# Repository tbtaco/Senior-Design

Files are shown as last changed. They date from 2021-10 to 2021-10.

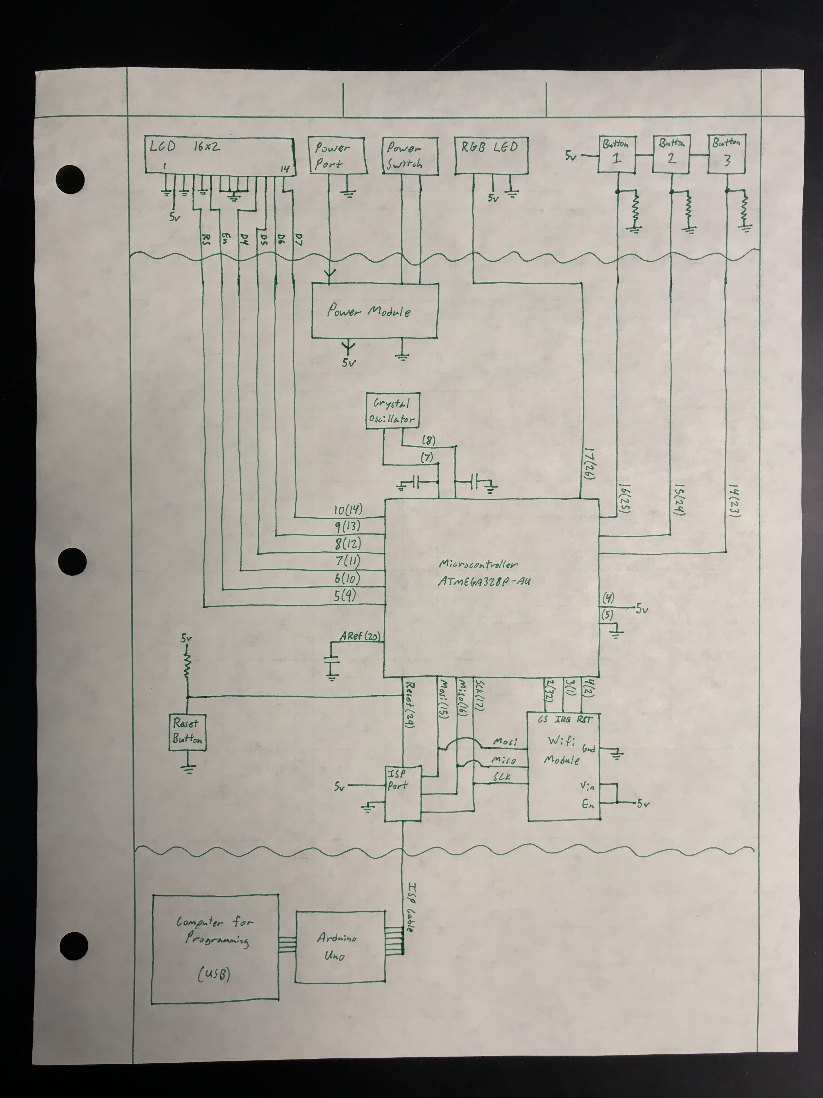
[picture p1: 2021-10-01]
Other Resources/Hand Drawn Early Schematic.jpeg

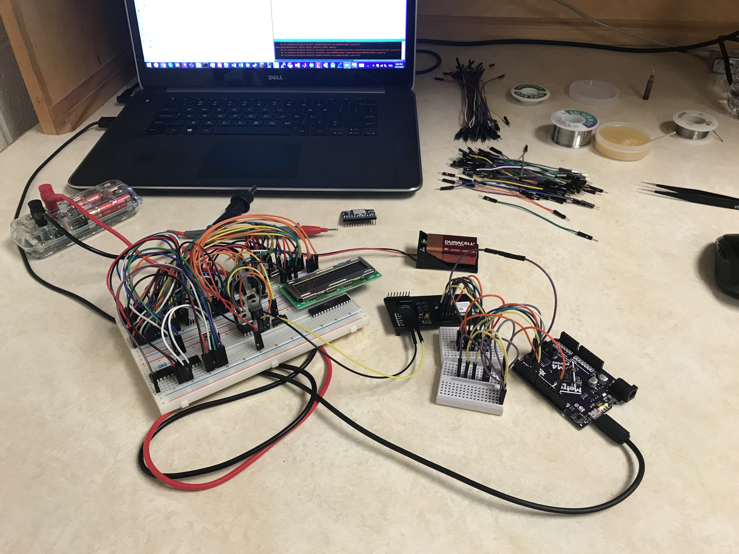
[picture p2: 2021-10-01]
Other Resources/Testing Proto 1.JPG

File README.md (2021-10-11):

The Senior Design project I was able to be a part of in Fall 2019 and Spring 2020 at K-State was the "MAC Address Finder".  For that, I worked in a group of 4 to fully design and build our device.  My role was mainly designing the circuit and building the board containing the microcontroller, and the board with the Wi-Fi module.  The device is needed in the residence halls for IT staff to quickly get certain device's MAC addresses.  The main reason for needing this device is the Google Home Mini.  They normally don't have a printed MAC address on the outside of the product and must be connected to a network to retrieve the address.  Our device creates that network to connect to and gives a very easy way to see this address.  The MAC address can then be used to manually add the device to the university network.

Schematics and board layouts can be found in the [EAGLE](https://github.com/tbtaco/Senior-Design/tree/main/EAGLE) directory.  The 3 main folders in there represent the separate orders I placed.  The final versions of each board I designed are:

[Main Board](https://github.com/tbtaco/Senior-Design/tree/main/EAGLE/Batch%201/Main%20Board) - This was the first version of the main PCB and I intended on redoing it at some point but it never happened due to budget constraints, time constraints, and Covid-19's impact on everything.
    
[Wifi Board](https://github.com/tbtaco/Senior-Design/tree/main/EAGLE/Batch%203/Wifi%20Board%20Rework) - I had the Wi-Fi portion working on a breadboard for the most part and turned that into a PCB.  There were some inconsistencies with different online documentation that messed up a couple things with my first version of the Wi-Fi board PCB.  We didn't have time for several attempts so I designed some breakout boards to test things before ordering the final version of this board.  The final version has several switches for debugging just in case things went horribly wrong which could easily be removed if another version were possibe.
    
[Button Board](https://github.com/tbtaco/Senior-Design/tree/main/EAGLE/Batch%201/Button%20Board) - A rather simple board that has an RGB LED and 3 buttons for input.
    
[Programmer Board](https://github.com/tbtaco/Senior-Design/tree/main/EAGLE/Batch%202/Programmer%20Board) - After several redesigns, this is the final board I created to assist with programming the microcontroller and Wi-Fi module.  It fits on top of an Arduino Uno for programming the microcontroller, and on top of a Metro M4 Express for programming the Wi-Fi module.

I also wrote the code to go on the microcontroller.  I hadn't intended on writing the final code for this project but it sort of just happened as I needed it for testing and we were short on time toward the end of semester.  This Arduino file along with the two edited programs for programming the boards can be found in the [Arduino](https://github.com/tbtaco/Senior-Design/tree/main/Arduino) directory.

I have some additional pictures and screenshots that don't fit in one of the two categories above, so I put them in the [Other Resources](https://github.com/tbtaco/Senior-Design/tree/main/Other%20Resources) directory.

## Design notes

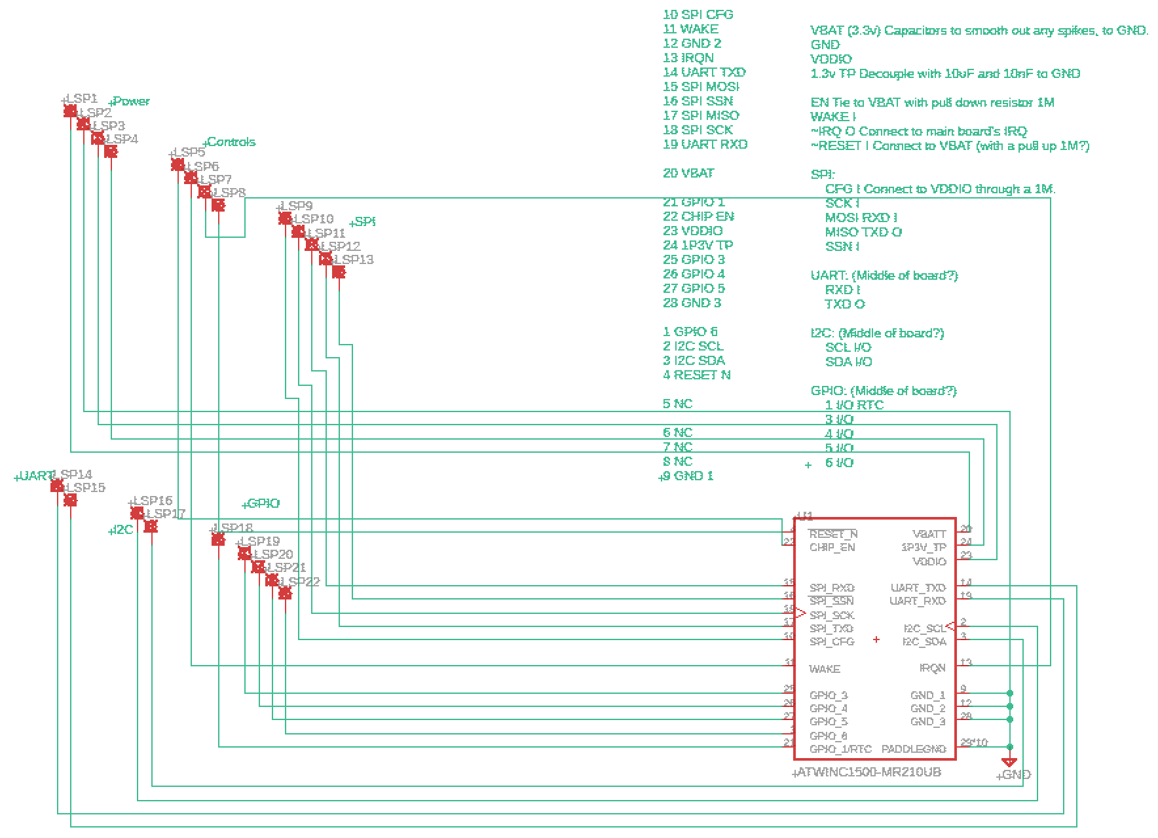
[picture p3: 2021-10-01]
EAGLE/Batch 2/Wifi Module Breakout/Wifi Module Breakout Schematic.png

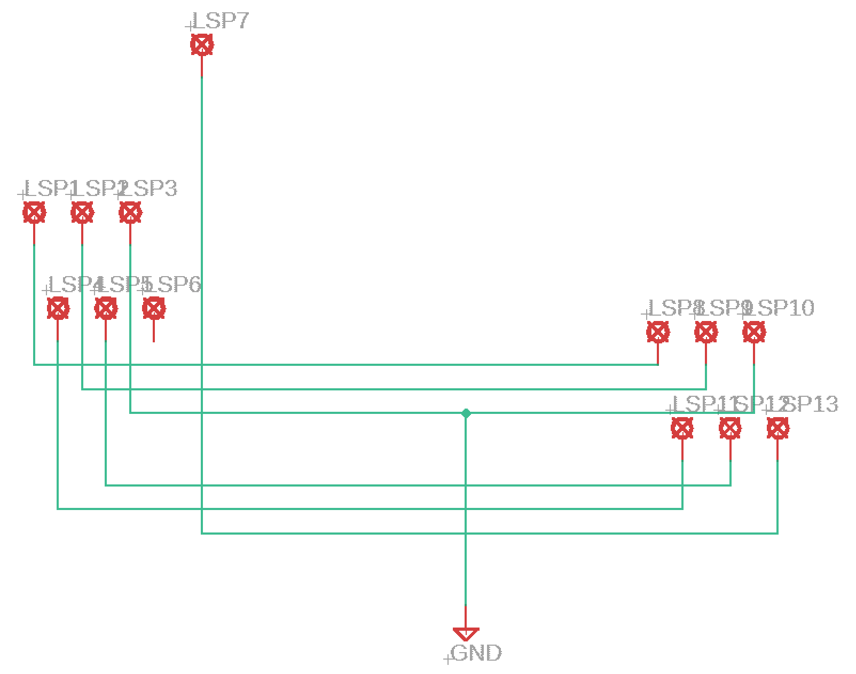
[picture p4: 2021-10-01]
EAGLE/Batch 1/Programmer Board/Programmer Board Schematic.png

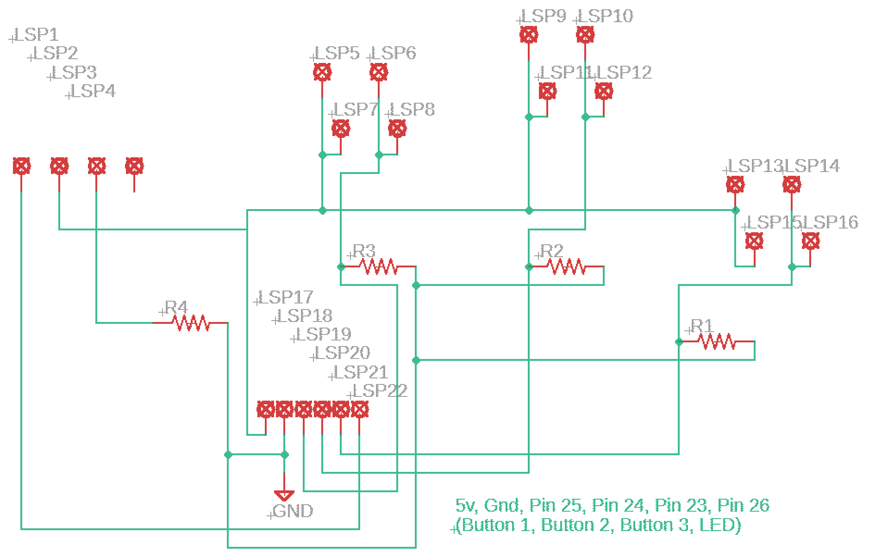
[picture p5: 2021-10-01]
EAGLE/Batch 1/Button Board/Button Board Schematic.png

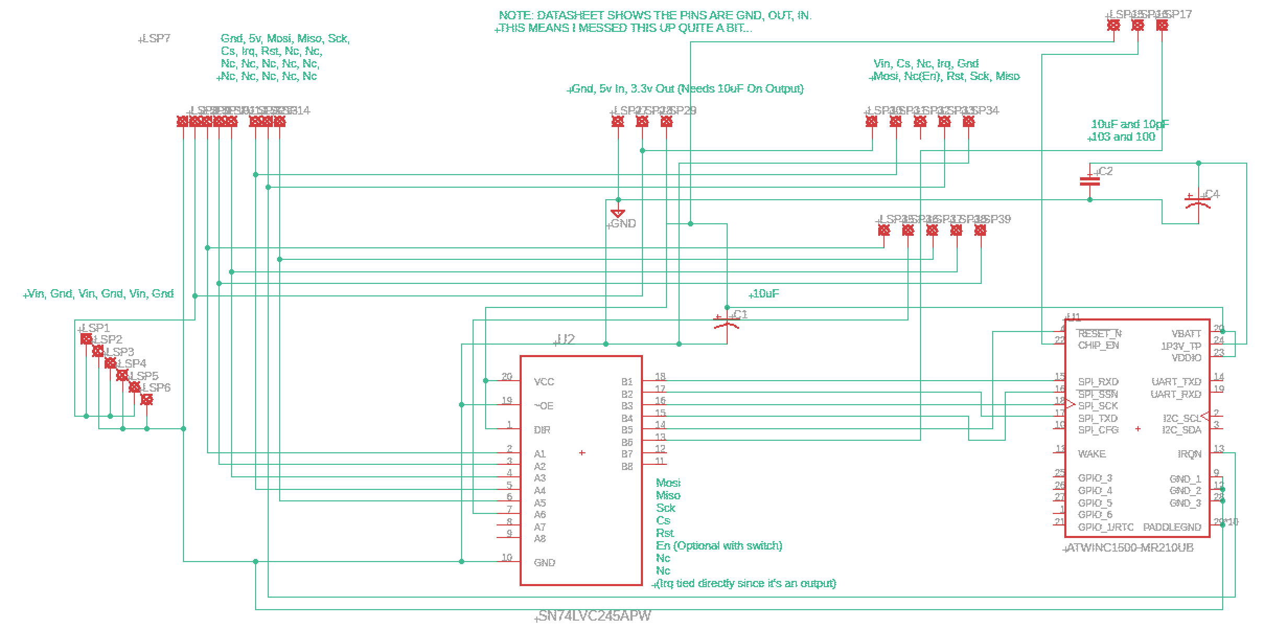
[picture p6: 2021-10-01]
EAGLE/Batch 1/Wifi Board/Wifi Board Schematic.png

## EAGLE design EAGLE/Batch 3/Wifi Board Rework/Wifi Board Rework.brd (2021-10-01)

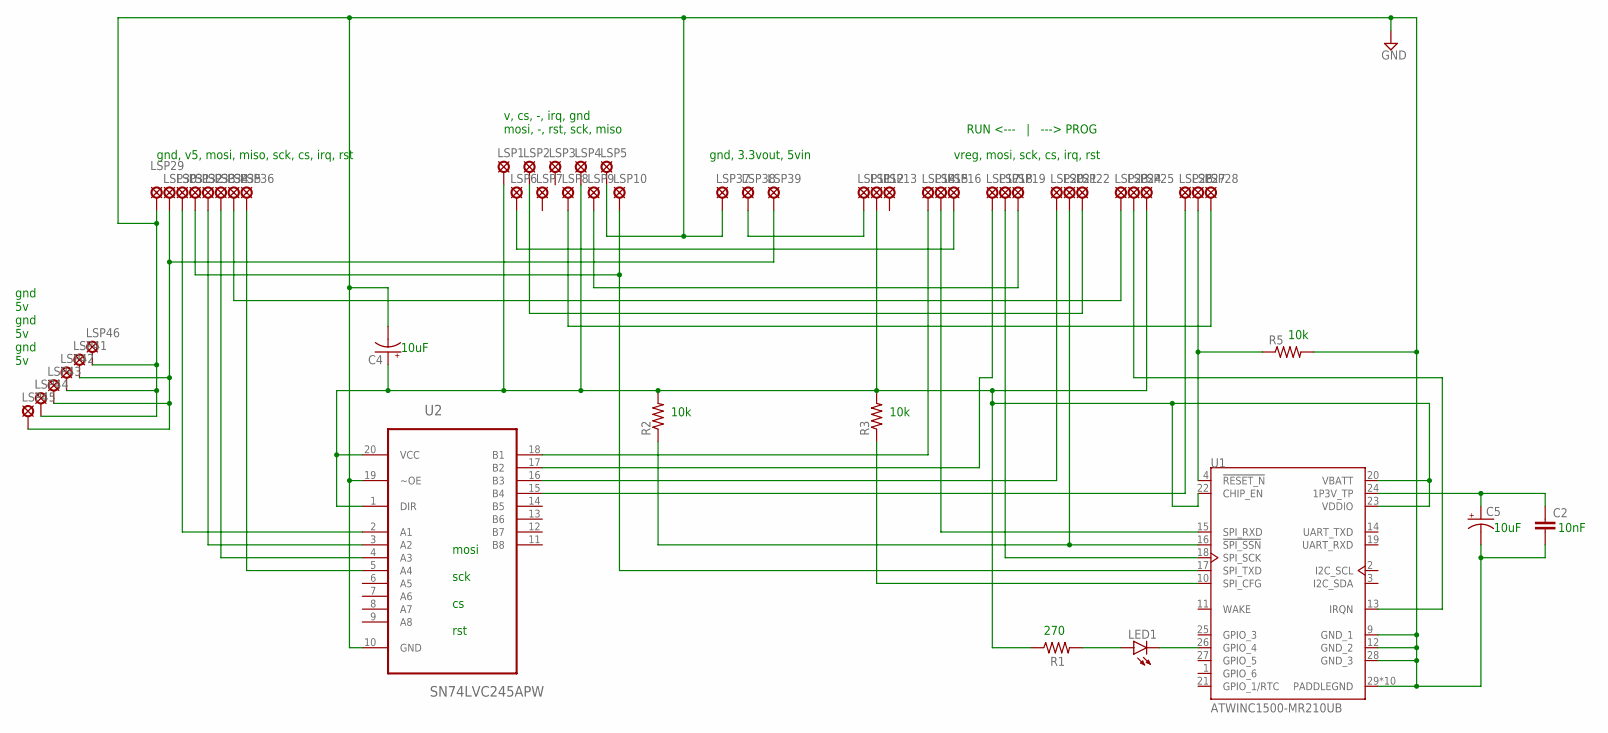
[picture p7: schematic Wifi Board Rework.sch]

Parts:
C2: C5/2.5; C5B2.5
C4, C5: CPOL-USE2-4; E2-4
LED1: LED5MM
LSP1, LSP2, LSP3, LSP4, LSP5, LSP7, LSP8, LSP9, LSP10, LSP11, LSP12, LSP13, LSP14, LSP15, LSP16, LSP17, LSP18, LSP19, LSP20, LSP21, LSP22, LSP23, LSP24, LSP25, LSP26, LSP27, LSP28, LSP30, LSP31, LSP32, LSP33, LSP34, LSP35, LSP36, LSP38, LSP39, LSP41, LSP42, LSP43, LSP44, LSP45: LSP10_CLSP10_C; LSP10_C
LSP6, LSP29, LSP37, LSP46: LSP10_S
R1, R2, R3, R5: R-US_VMTA55; VMTA55
U1: ATWINC1500-MR210UB; MICROCHIP_ATWINC1500-MR210UB
U2: SN74LVC245APW; SOP65P640X120-20N

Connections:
GND: C2.2, C4.-, C5.-, LSP5.P$1, LSP29.P$1, LSP37.P$1, LSP42.P$1, LSP44.P$1, LSP46.P$1, R5.2, U1.9 (GND_1), U1.12 (GND_2), U1.28 (GND_3), U1.29 (PADDLEGND), U1.P$1 (PADDLEGND), U1.P$2 (PADDLEGND), U1.P$3 (PADDLEGND), U1.P$4 (PADDLEGND), U1.P$5 (PADDLEGND), U1.P$6 (PADDLEGND), U1.P$7 (PADDLEGND), U1.P$8 (PADDLEGND), U1.P$9 (PADDLEGND), U2.10 (GND), U2.19 (~OE)
unnamed: LED1.K (C), U1.26 (GPIO_4)
unnamed: LED1.A, R1.2
unnamed: C4.+, LSP1.P$1, LSP4.P$1, LSP12.P$1, LSP25.P$1, R1.1, R2.2, R3.2, U1.20 (VBATT), U1.22 (CHIP_EN), U1.23 (VDDIO), U2.1 (DIR), U2.20 (VCC)
unnamed: LSP11.P$1, LSP38.P$1
unnamed: R3.1, U1.10 (SPI_CFG)
unnamed: LSP10.P$1, LSP32.P$1, U1.17 (SPI_TXD)
unnamed: LSP30.P$1, LSP39.P$1, LSP41.P$1, LSP43.P$1, LSP45.P$1
unnamed: LSP23.P$1, LSP35.P$1
unnamed: LSP15.P$1, U1.15 (SPI_RXD)
unnamed: LSP6.P$1, LSP16.P$1
unnamed: LSP9.P$1, LSP19.P$1
unnamed: LSP2.P$1, LSP22.P$1
unnamed: LSP24.P$1, U1.13 (IRQN)
unnamed: C2.1, C5.+, U1.24 (1P3V_TP)
unnamed: LSP14.P$1, U2.18 (B1)
unnamed: LSP17.P$1, U2.17 (B2)
unnamed: LSP20.P$1, U2.16 (B3)
unnamed: LSP26.P$1, U2.15 (B4)
unnamed: LSP27.P$1, R5.1, U1.4 (!RESET_N)
unnamed: LSP34.P$1, U2.4 (A3)
unnamed: LSP18.P$1, U1.18 (SPI_SCK)
unnamed: LSP21.P$1, R2.1, U1.16 (!SPI_SSN)
unnamed: LSP36.P$1, U2.5 (A4)
unnamed: LSP33.P$1, U2.3 (A2)
unnamed: LSP31.P$1, U2.2 (A1)
unnamed: LSP8.P$1, LSP28.P$1

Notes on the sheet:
v, cs, -, irq, gnd mosi, -, rst, sck, miso
vreg, mosi, sck, cs, irq, rst
gnd, v5, mosi, miso, sck, cs, irq, rst
10k
10uF
10nF
270
gnd, 3.3vout, 5vin
RUN <--- | ---> PROG
gnd 5v gnd 5v gnd 5v
mosi sck cs rst

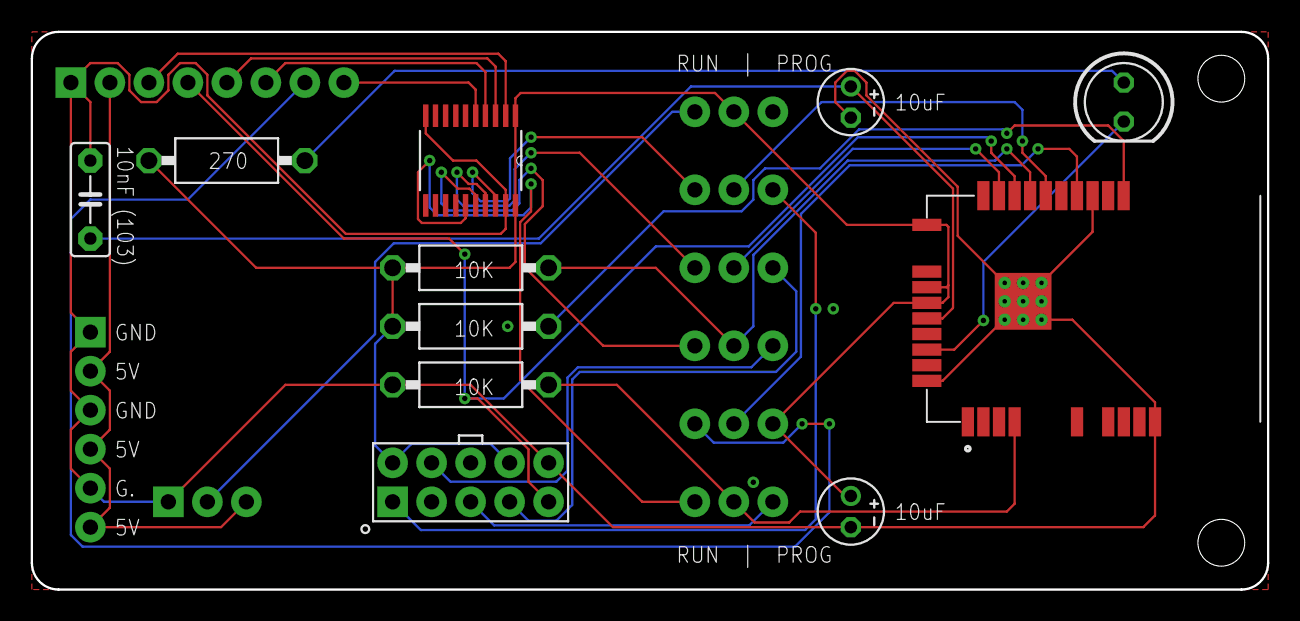
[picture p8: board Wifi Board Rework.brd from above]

Board: 2 copper layers, 80.5 x 36.3 mm, 55 parts (0 on the bottom side), 27 nets.

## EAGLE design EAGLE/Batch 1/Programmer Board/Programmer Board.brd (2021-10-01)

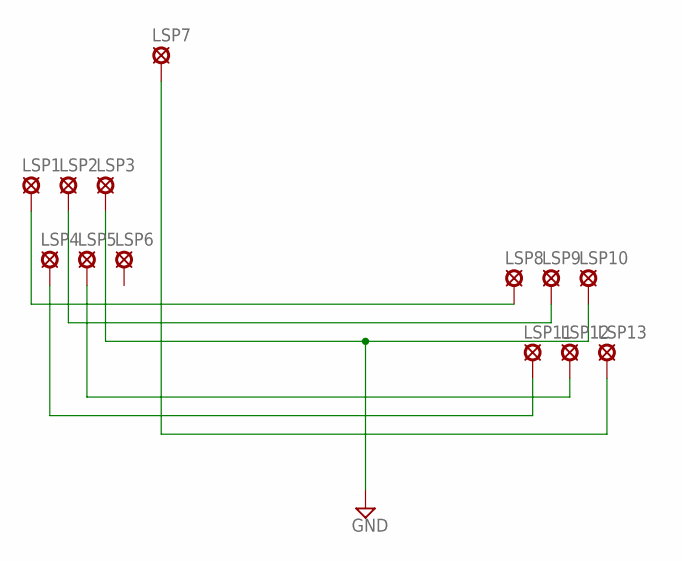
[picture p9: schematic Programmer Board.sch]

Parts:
LSP1, LSP2, LSP3, LSP4, LSP5, LSP6, LSP7, LSP8, LSP9, LSP10, LSP11, LSP12, LSP13: LSP10_CLSP10_C; LSP10_C

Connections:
GND: LSP3.P$1, LSP10.P$1
unnamed: LSP1.P$1, LSP8.P$1
unnamed: LSP2.P$1, LSP9.P$1
unnamed: LSP4.P$1, LSP11.P$1
unnamed: LSP5.P$1, LSP12.P$1
unnamed: LSP7.P$1, LSP13.P$1

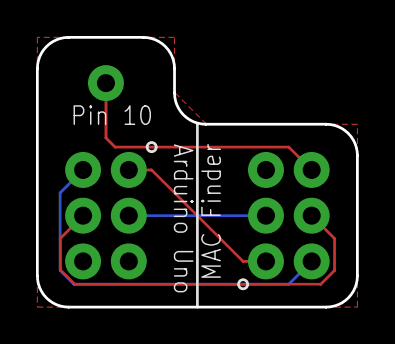
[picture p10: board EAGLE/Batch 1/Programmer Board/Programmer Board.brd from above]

Board: 2 copper layers, 17.8 x 15.0 mm, 13 parts (0 on the bottom side), 6 nets.

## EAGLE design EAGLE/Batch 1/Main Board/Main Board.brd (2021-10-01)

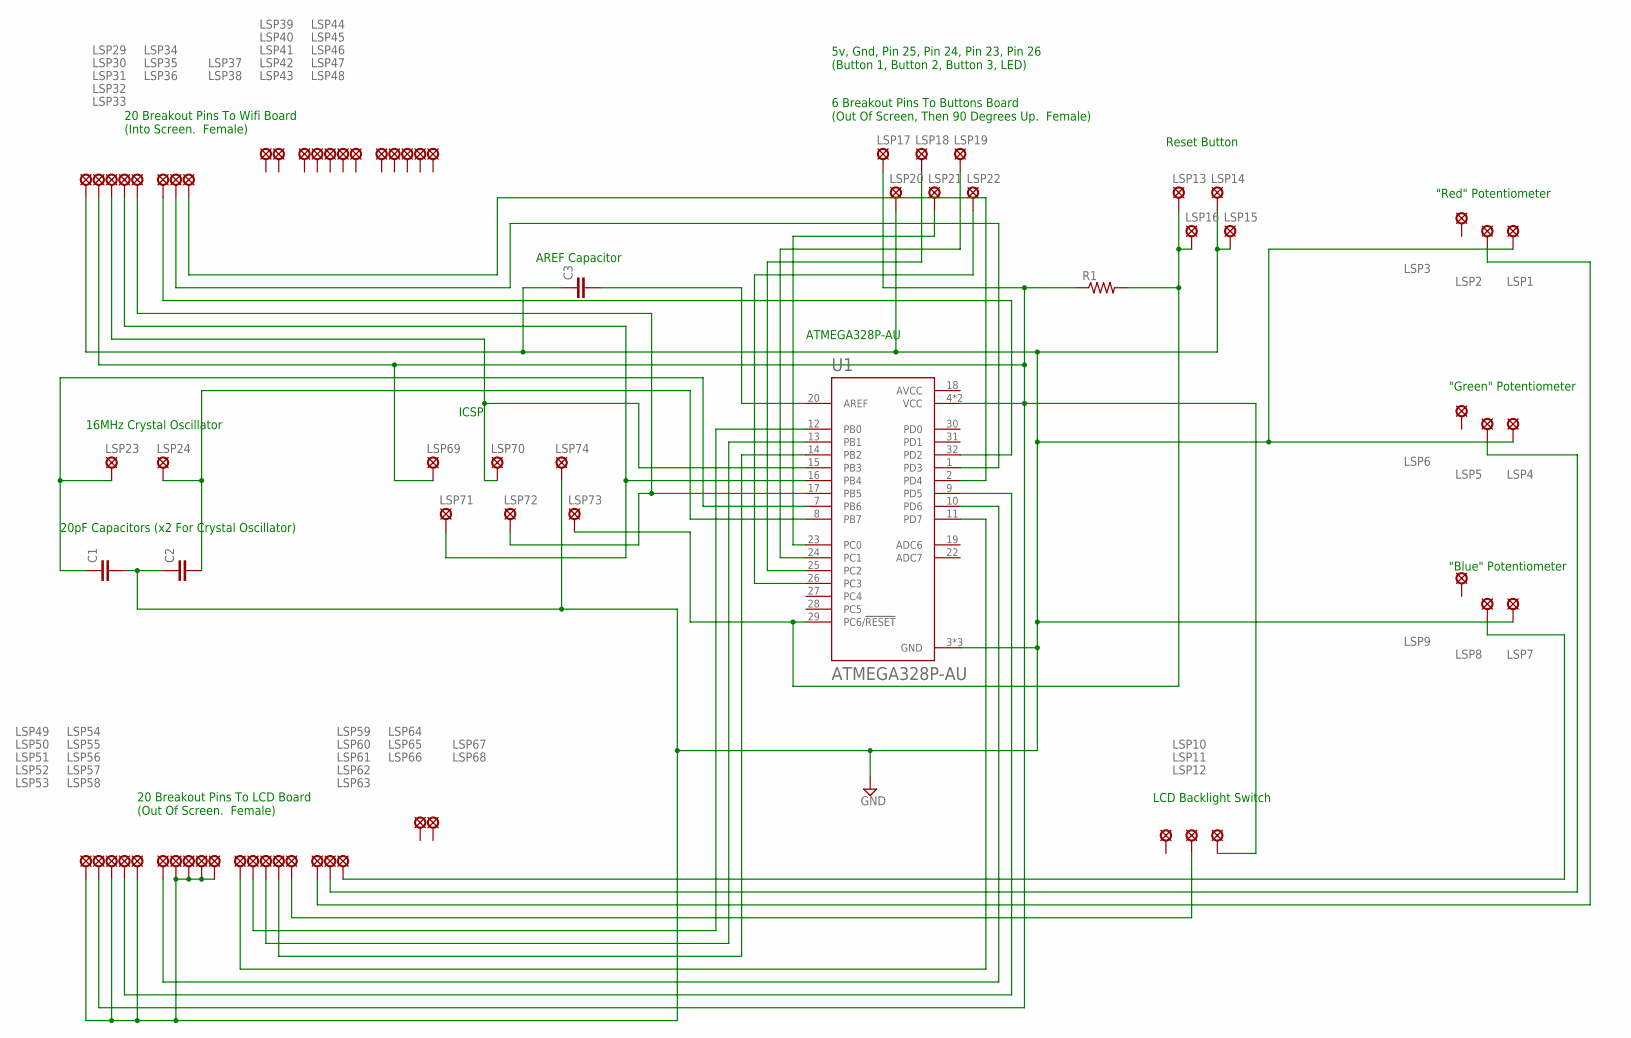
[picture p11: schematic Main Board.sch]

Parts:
C1, C2, C3: C5/2.5; C5B2.5
LSP1, LSP2, LSP3, LSP4, LSP5, LSP6, LSP7, LSP8, LSP9, LSP10, LSP11, LSP12, LSP13, LSP14, LSP15, LSP16, LSP17, LSP18, LSP19, LSP20, LSP21, LSP22, LSP23, LSP24, LSP29, LSP30, LSP31, LSP32, LSP33, LSP34, LSP35, LSP36, LSP37, LSP38, LSP39, LSP40, LSP41, LSP42, LSP43, LSP44, LSP45, LSP46, LSP47, LSP48, LSP49, LSP50, LSP51, LSP52, LSP53, LSP54, LSP55, LSP56, LSP57, LSP58, LSP59, LSP60, LSP61, LSP62, LSP63, LSP64, LSP65, LSP66, LSP67, LSP68, LSP69, LSP70, LSP71, LSP72, LSP73, LSP74: LSP10_CLSP10_C; LSP10_C
R1: R-US_VMTA55; VMTA55
U1: ATMEGA328P-AU; QFP80P900X900X120-32N

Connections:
AVCC: U1.18 (AVCC)
GND: C1.2, C2.1, C3.1, LSP1.P$1, LSP4.P$1, LSP7.P$1, LSP14.P$1, LSP15.P$1, LSP20.P$1, LSP29.P$1, LSP49.P$1, LSP51.P$1, LSP53.P$1, LSP55.P$1, LSP56.P$1, LSP57.P$1, LSP58.P$1, LSP74.P$1, U1.3 (GND), U1.5 (GND), U1.21 (GND)
unnamed: LSP2.P$1, LSP64.P$1
unnamed: LSP31.P$1, LSP70.P$1, U1.15 (PB3)
unnamed: LSP5.P$1, LSP65.P$1
unnamed: C1.1, LSP23.P$1, U1.7 (PB6)
unnamed: C2.2, LSP24.P$1, U1.8 (PB7)
unnamed: LSP8.P$1, LSP66.P$1
unnamed: LSP33.P$1, LSP72.P$1, U1.17 (PB5)
unnamed: LSP32.P$1, LSP71.P$1, U1.16 (PB4)
unnamed: LSP13.P$1, LSP16.P$1, LSP73.P$1, R1.2, U1.29 (PC6/!RESET)
unnamed: LSP22.P$1, U1.26 (PC3)
unnamed: LSP18.P$1, U1.25 (PC2)
unnamed: LSP19.P$1, U1.24 (PC1)
unnamed: LSP52.P$1, U1.9 (PD5)
unnamed: LSP54.P$1, U1.10 (PD6)
unnamed: LSP59.P$1, U1.11 (PD7)
unnamed: LSP60.P$1, U1.12 (PB0)
unnamed: LSP61.P$1, U1.13 (PB1)
unnamed: LSP62.P$1, U1.14 (PB2)
unnamed: LSP11.P$1, LSP63.P$1
unnamed: LSP12.P$1, LSP17.P$1, LSP30.P$1, LSP50.P$1, LSP69.P$1, R1.1, U1.4 (VCC), U1.6 (VCC)
unnamed: LSP21.P$1, U1.23 (PC0)
unnamed: C3.2, U1.20 (AREF)
unnamed: LSP34.P$1, U1.32 (PD2)
unnamed: LSP35.P$1, U1.1 (PD3)
unnamed: LSP36.P$1, U1.2 (PD4)

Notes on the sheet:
ICSP
ATMEGA328P-AU
6 Breakout Pins To Buttons Board (Out Of Screen, Then 90 Degrees Up. Female)
20 Breakout Pins To Wifi Board (Into Screen. Female)
20 Breakout Pins To LCD Board (Out Of Screen. Female)
16MHz Crystal Oscillator
20pF Capacitors (x2 For Crystal Oscillator)
Reset Button
"Red" Potentiometer
"Green" Potentiometer
"Blue" Potentiometer
LCD Backlight Switch
AREF Capacitor
5v, Gnd, Pin 25, Pin 24, Pin 23, Pin 26 (Button 1, Button 2, Button 3, LED)

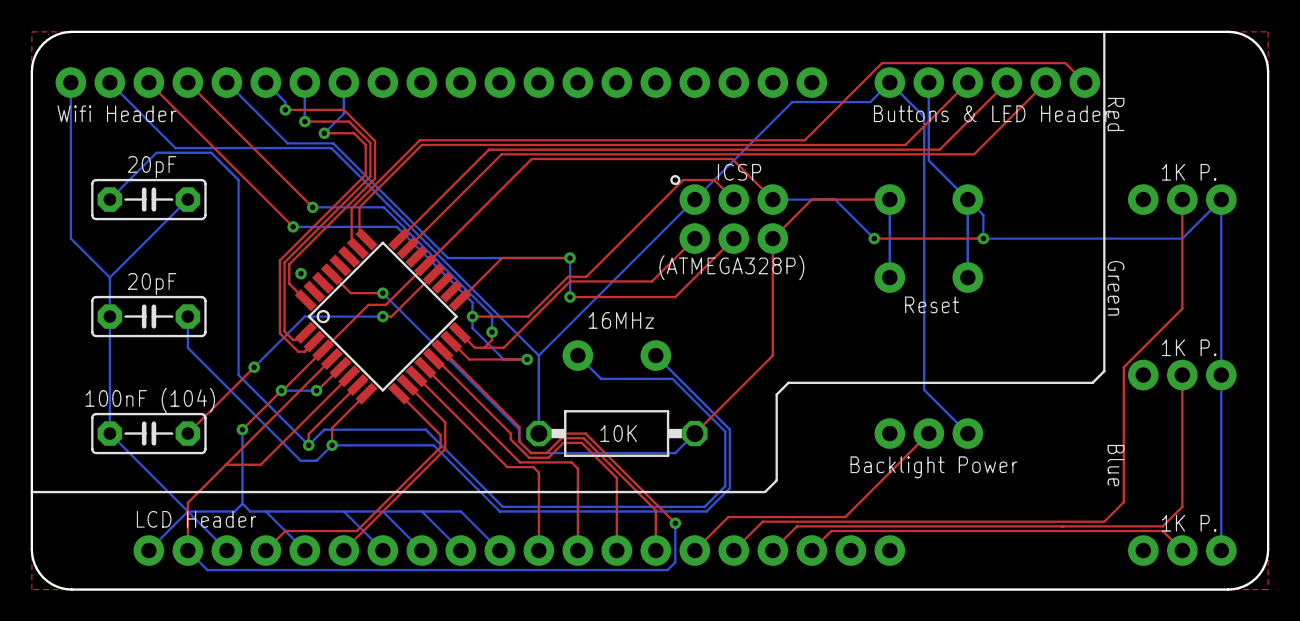
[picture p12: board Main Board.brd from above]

Board: 2 copper layers, 80.5 x 36.3 mm, 75 parts (0 on the bottom side), 26 nets.

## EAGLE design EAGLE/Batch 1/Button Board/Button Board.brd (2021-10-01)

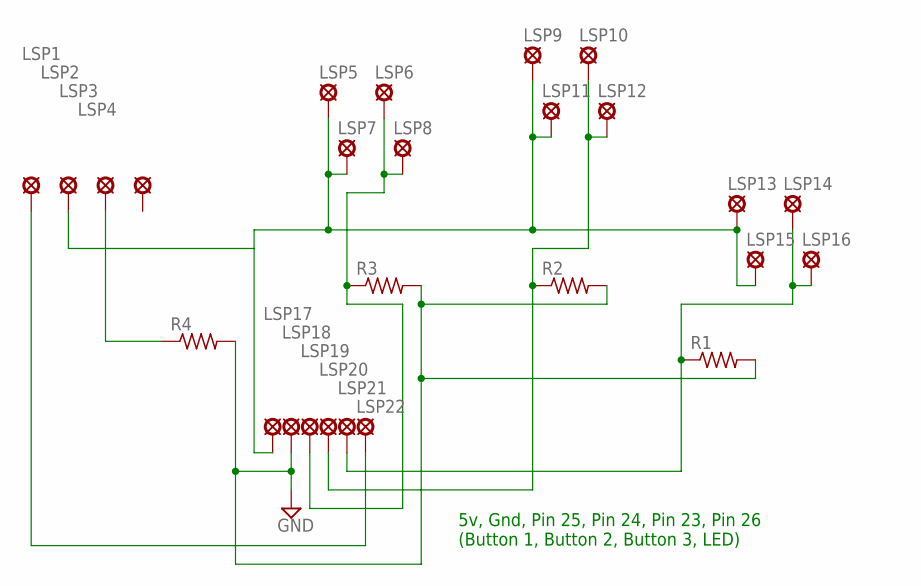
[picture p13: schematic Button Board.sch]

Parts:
LSP1, LSP2, LSP3, LSP4, LSP5, LSP6, LSP7, LSP8, LSP9, LSP10, LSP11, LSP12, LSP13, LSP14, LSP15, LSP16, LSP17, LSP18, LSP19, LSP20, LSP21, LSP22: LSP10_CLSP10_C; LSP10_C
R1, R2, R3, R4: R-US_VMTA55; VMTA55

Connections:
GND: LSP18.P$1, R1.2, R2.2, R3.2, R4.2
unnamed: LSP6.P$1, LSP8.P$1, LSP19.P$1, R3.1
unnamed: LSP3.P$1, R4.1
unnamed: LSP10.P$1, LSP12.P$1, LSP20.P$1, R2.1
unnamed: LSP2.P$1, LSP5.P$1, LSP7.P$1, LSP9.P$1, LSP11.P$1, LSP13.P$1, LSP15.P$1, LSP17.P$1
unnamed: LSP14.P$1, LSP16.P$1, LSP21.P$1, R1.1
unnamed: LSP1.P$1, LSP22.P$1

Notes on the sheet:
5v, Gnd, Pin 25, Pin 24, Pin 23, Pin 26 (Button 1, Button 2, Button 3, LED)

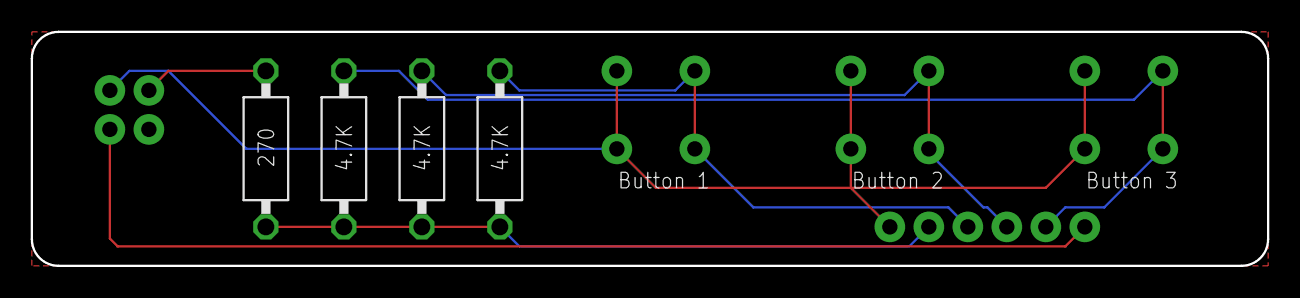
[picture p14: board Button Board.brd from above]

Board: 2 copper layers, 80.5 x 15.2 mm, 26 parts (0 on the bottom side), 7 nets.

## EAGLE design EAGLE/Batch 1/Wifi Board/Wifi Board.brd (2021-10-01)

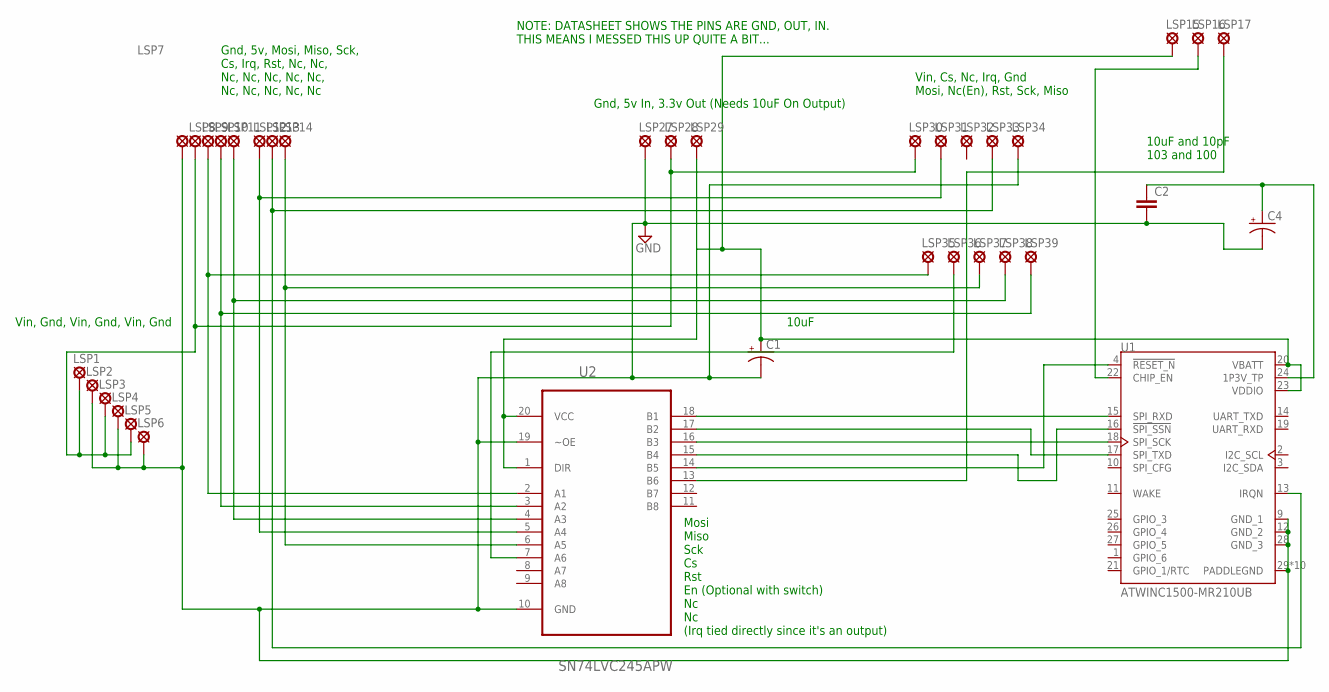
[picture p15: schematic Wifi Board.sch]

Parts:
C1, C4: CPOL-USE2-4; E2-4
C2: C5/2.5; C5B2.5
LSP1, LSP2, LSP3, LSP4, LSP5, LSP6, LSP7, LSP8, LSP9, LSP10, LSP11, LSP12, LSP13, LSP14, LSP15, LSP16, LSP17, LSP27, LSP28, LSP29, LSP30, LSP31, LSP32, LSP33, LSP34, LSP35, LSP36, LSP37, LSP38, LSP39: LSP10_CLSP10_C; LSP10_C
U1: ATWINC1500-MR210UB; MICROCHIP_ATWINC1500-MR210UB
U2: SN74LVC245APW; SOP65P640X120-20N

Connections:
GND: C1.-, C2.2, C4.-, LSP2.P$1, LSP4.P$1, LSP6.P$1, LSP7.P$1, LSP27.P$1, LSP34.P$1, U1.9 (GND_1), U1.12 (GND_2), U1.28 (GND_3), U1.29 (PADDLEGND), U1.P$1 (PADDLEGND), U1.P$2 (PADDLEGND), U1.P$3 (PADDLEGND), U1.P$4 (PADDLEGND), U1.P$5 (PADDLEGND), U1.P$6 (PADDLEGND), U1.P$7 (PADDLEGND), U1.P$8 (PADDLEGND), U1.P$9 (PADDLEGND), U2.10 (GND), U2.19 (~OE)
unnamed: LSP36.P$1, U2.7 (A6)
unnamed: LSP1.P$1, LSP3.P$1, LSP5.P$1, LSP8.P$1, LSP28.P$1, LSP30.P$1
unnamed: C1.+, LSP15.P$1, LSP29.P$1, U1.20 (VBATT), U1.23 (VDDIO), U2.1 (DIR), U2.20 (VCC)
unnamed: LSP9.P$1, LSP35.P$1, U2.2 (A1)
unnamed: LSP10.P$1, LSP39.P$1, U2.3 (A2)
unnamed: LSP11.P$1, LSP38.P$1, U2.4 (A3)
unnamed: LSP12.P$1, LSP31.P$1, U2.5 (A4)
unnamed: LSP13.P$1, LSP33.P$1, U1.13 (IRQN)
unnamed: LSP14.P$1, LSP37.P$1, U2.6 (A5)
unnamed: U1.15 (SPI_RXD), U2.18 (B1)
unnamed: U1.17 (SPI_TXD), U2.17 (B2)
unnamed: U1.18 (SPI_SCK), U2.16 (B3)
unnamed: U1.16 (!SPI_SSN), U2.15 (B4)
unnamed: LSP17.P$1, U2.13 (B6)
unnamed: U1.4 (!RESET_N), U2.14 (B5)
unnamed: LSP16.P$1, U1.22 (CHIP_EN)
unnamed: C2.1, C4.+, U1.24 (1P3V_TP)

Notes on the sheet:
Gnd, 5v, Mosi, Miso, Sck, Cs, Irq, Rst, Nc, Nc, Nc, Nc, Nc, Nc, Nc, Nc, Nc, Nc, Nc, Nc
Gnd, 5v In, 3.3v Out (Needs 10uF On Output)
Vin, Cs, Nc, Irq, Gnd Mosi, Nc(En), Rst, Sck, Miso
Vin, Gnd, Vin, Gnd, Vin, Gnd
10uF
Mosi Miso Sck Cs Rst En (Optional with switch) Nc Nc (Irq tied directly since it's an output)
10uF and 10pF 103 and 100
NOTE: DATASHEET SHOWS THE PINS ARE GND, OUT, IN. THIS MEANS I MESSED THIS UP QUITE A BIT...

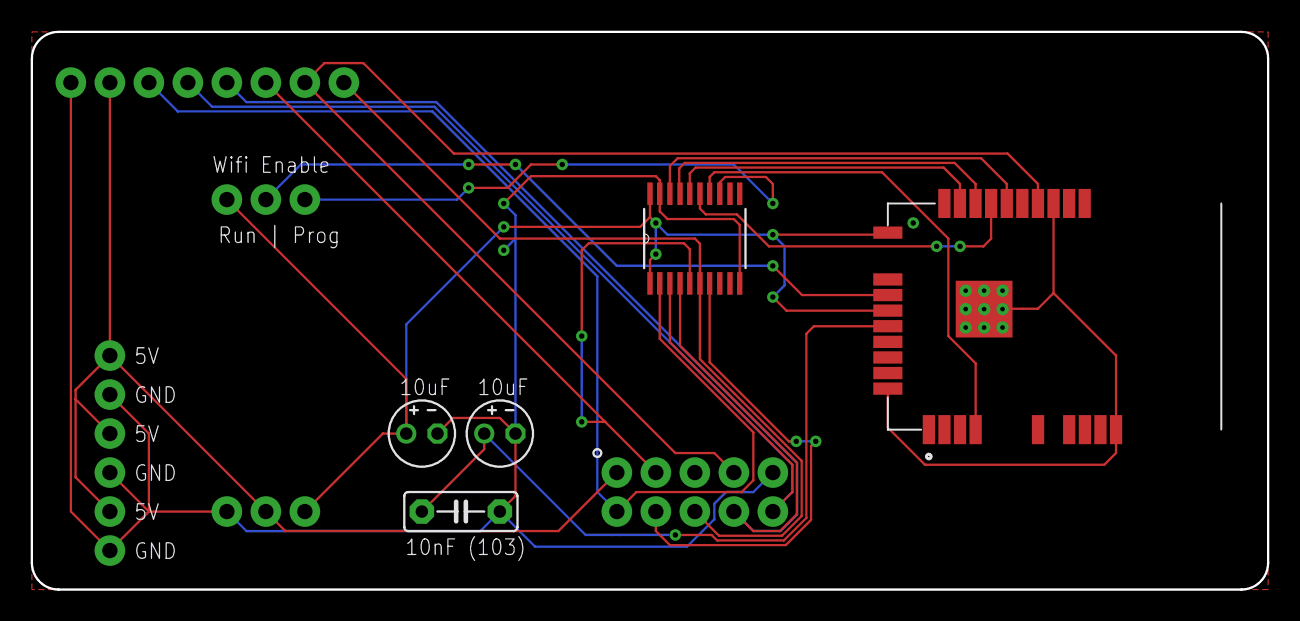
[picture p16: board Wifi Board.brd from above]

Board: 2 copper layers, 80.5 x 36.3 mm, 35 parts (0 on the bottom side), 18 nets.

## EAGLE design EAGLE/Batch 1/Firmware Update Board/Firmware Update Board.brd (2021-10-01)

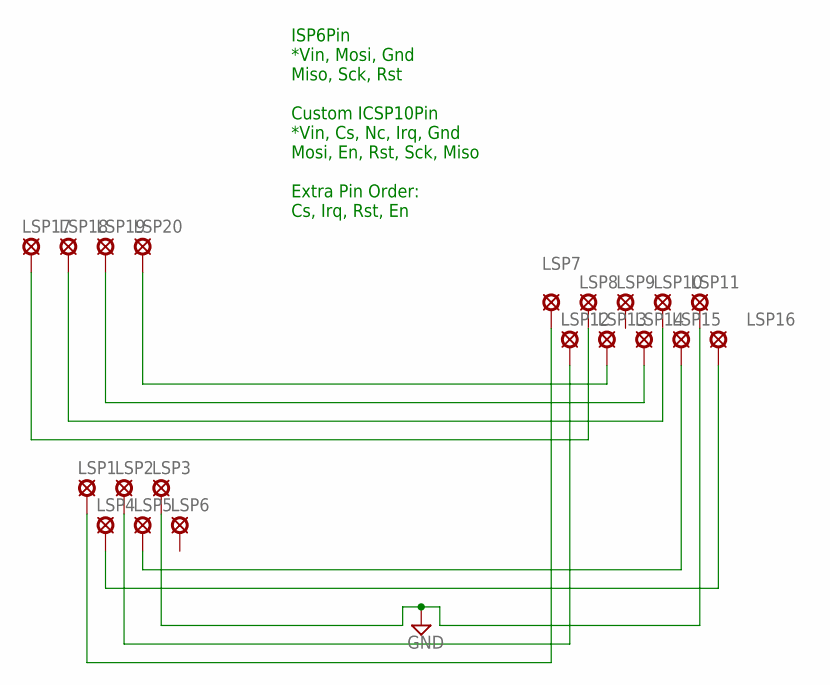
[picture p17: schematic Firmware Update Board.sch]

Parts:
LSP1, LSP2, LSP3, LSP4, LSP5, LSP6, LSP7, LSP8, LSP9, LSP10, LSP11, LSP12, LSP13, LSP14, LSP15, LSP16, LSP17, LSP18, LSP19, LSP20: LSP10_CLSP10_C; LSP10_C

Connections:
GND: LSP3.P$1, LSP11.P$1
unnamed: LSP1.P$1, LSP7.P$1
unnamed: LSP2.P$1, LSP12.P$1
unnamed: LSP4.P$1, LSP16.P$1
unnamed: LSP5.P$1, LSP15.P$1
unnamed: LSP13.P$1, LSP20.P$1
unnamed: LSP14.P$1, LSP19.P$1
unnamed: LSP10.P$1, LSP18.P$1
unnamed: LSP8.P$1, LSP17.P$1

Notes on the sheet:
ISP6Pin *Vin, Mosi, Gnd Miso, Sck, Rst Custom ICSP10Pin *Vin, Cs, Nc, Irq, Gnd Mosi, En, Rst, Sck, Miso Extra Pin Order: Cs, Irq, Rst, En

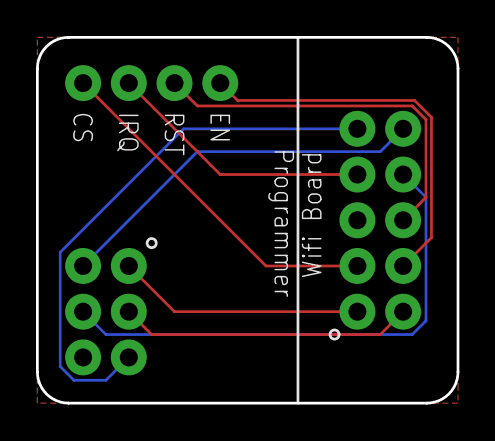
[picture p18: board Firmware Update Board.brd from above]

Board: 2 copper layers, 23.4 x 20.3 mm, 20 parts (0 on the bottom side), 9 nets.

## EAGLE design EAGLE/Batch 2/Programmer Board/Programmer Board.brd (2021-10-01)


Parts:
LSP1, LSP2, LSP3, LSP28, LSP29: LSP10_S
LSP4, LSP5, LSP6, LSP7, LSP8, LSP9, LSP11, LSP12, LSP13, LSP14, LSP15, LSP16, LSP17, LSP18, LSP19, LSP20, LSP21, LSP22, LSP23, LSP24, LSP25, LSP26, LSP27, LSP30: LSP10_CLSP10_C; LSP10_C

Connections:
GND: LSP8.P$1, LSP14.P$1, LSP16.P$1, LSP19.P$1, LSP23.P$1
unnamed: LSP5.P$1, LSP11.P$1, LSP20.P$1
unnamed: LSP27.P$1, LSP30.P$1
unnamed: LSP28.P$1, LSP29.P$1
unnamed: LSP1.P$1, LSP6.P$1, LSP12.P$1
unnamed: LSP2.P$1, LSP3.P$1, LSP22.P$1
unnamed: LSP4.P$1, LSP9.P$1, LSP15.P$1
unnamed: LSP17.P$1, LSP24.P$1
unnamed: LSP21.P$1, LSP25.P$1
unnamed: LSP13.P$1, LSP18.P$1, LSP26.P$1

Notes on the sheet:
GND MISO IRQ SCK NOTCH NC RST CS NC V MOSI DOT
GND RST NOTCH MOSI SCK V MISO DOT
Rx (Pin 0) Tx (Pin 1)
CS (4) IRQ (3) RST (2) Tx (1) Rx (0)
DOT MISO V SCK MOSI NOTCH RST GND
NOTE: Do not use the RST pin on this header. It is RST for the programmer, not the device being programmed!
NOTE: Any NC pins I will be connecting to GND.
NOTE: LEAVE THIS FLOATING!


Board: 2 copper layers, 18.3 x 31.2 mm, 29 parts (0 on the bottom side), 10 nets.

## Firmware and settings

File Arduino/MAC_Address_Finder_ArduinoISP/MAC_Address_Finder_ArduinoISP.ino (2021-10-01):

/*
 * MAC Address Finder Edited ArduinoISP Program
 * This program should be uploaded to an Arduino Uno and is used to re-program the MAC Address Finder Main Board (ATMEGA328P-AU)
 * Any questions can be sent to Tyler Richey at tyler777@ksu.edu or tbtaco@hotmail.com
 */

// ArduinoISP
// Copyright (c) 2008-2011 Randall Bohn
// If you require a license, see
// http://www.opensource.org/licenses/bsd-license.php
//
// This sketch turns the Arduino into a AVRISP using the following Arduino pins:
//
// Pin 10 is used to reset the target microcontroller.
//
// By default, the hardware SPI pins MISO, MOSI and SCK are used to communicate
// with the target. On all Arduinos, these pins can be found
// on the ICSP/SPI header:
//
//               MISO °. . 5V (!) Avoid this pin on Due, Zero...
//               SCK   . . MOSI
//                     . . GND
//
// On some Arduinos (Uno,...), pins MOSI, MISO and SCK are the same pins as
// digital pin 11, 12 and 13, respectively. That is why many tutorials instruct
// you to hook up the target to these pins. If you find this wiring more
// practical, have a define USE_OLD_STYLE_WIRING. This will work even when not
// using an Uno. (On an Uno this is not needed).
//
// Alternatively you can use any other digital pin by configuring
// software ('BitBanged') SPI and having appropriate defines for PIN_MOSI,
// PIN_MISO and PIN_SCK.
//
// IMPORTANT: When using an Arduino that is not 5V tolerant (Due, Zero, ...) as
// the programmer, make sure to not expose any of the programmer's pins to 5V.
// A simple way to accomplish this is to power the complete system (programmer
// and target) at 3V3.
//
// Put an LED (with resistor) on the following pins:
// 9: Heartbeat   - shows the programmer is running
// 8: Error       - Lights up if something goes wrong (use red if that makes sense)
// 7: Programming - In communication with the slave
//

#include "Arduino.h"
#undef SERIAL


#define PROG_FLICKER true

// Configure SPI clock (in Hz).
// E.g. for an ATtiny @ 128 kHz: the datasheet states that both the high and low
// SPI clock pulse must be > 2 CPU cycles, so take 3 cycles i.e. divide target
// f_cpu by 6:
//     #define SPI_CLOCK            (128000/6)
//
// A clock slow enough for an ATtiny85 @ 1 MHz, is a reasonable default:

#define SPI_CLOCK 		(1000000/6)


// Select hardware or software SPI, depending on SPI clock.
// Currently only for AVR, for other architectures (Due, Zero,...), hardware SPI
// is probably too fast anyway.

#if defined(ARDUINO_ARCH_AVR)

#if SPI_CLOCK > (F_CPU / 128)
#define USE_HARDWARE_SPI
#endif

#endif

// Configure which pins to use:

// The standard pin configuration.
#ifndef ARDUINO_HOODLOADER2

//#define RESET     10 // Use pin 10 to reset the target rather than SS
#define RESET     2 // MAC Address Finder Edit
#define LED_HB    9
#define LED_ERR   8
#define LED_PMODE 7

// Uncomment following line to use the old Uno style wiring
// (using pin 11, 12 and 13 instead of the SPI header) on Leonardo, Due...

// #define USE_OLD_STYLE_WIRING

#ifdef USE_OLD_STYLE_WIRING

#define PIN_MOSI	11
#define PIN_MISO	12
#define PIN_SCK		13

#endif

// HOODLOADER2 means running sketches on the ATmega16U2 serial converter chips
// on Uno or Mega boards. We must use pins that are broken out:
#else

#define RESET     	4
#define LED_HB    	7
#define LED_ERR   	6
#define LED_PMODE 	5

#endif

// By default, use hardware SPI pins:
#ifndef PIN_MOSI
#define PIN_MOSI 	MOSI
#endif

#ifndef PIN_MISO
#define PIN_MISO 	MISO
#endif

#ifndef PIN_SCK
#define PIN_SCK 	SCK
#endif

// Force bitbanged SPI if not using the hardware SPI pins:
#if (PIN_MISO != MISO) ||  (PIN_MOSI != MOSI) || (PIN_SCK != SCK)
#undef USE_HARDWARE_SPI
#endif


// Configure the serial port to use.
//
// Prefer the USB virtual serial port (aka. native USB port), if the Arduino has one:
//   - it does not autoreset (except for the magic baud rate of 1200).
//   - it is more reliable because of USB handshaking.
//
// Leonardo and similar have an USB virtual serial port: 'Serial'.
// Due and Zero have an USB virtual serial port: 'SerialUSB'.
//
// On the Due and Zero, 'Serial' can be used too, provided you disable autoreset.
// To use 'Serial': #define SERIAL Serial

#ifdef SERIAL_PORT_USBVIRTUAL
#define SERIAL SERIAL_PORT_USBVIRTUAL
#else
#define SERIAL Serial
#endif


// Configure the baud rate:

#define BAUDRATE	19200
// #define BAUDRATE	115200
// #define BAUDRATE	1000000


#define HWVER 2
#define SWMAJ 1
#define SWMIN 18

// STK Definitions
#define STK_OK      0x10
#define STK_FAILED  0x11
#define STK_UNKNOWN 0x12
#define STK_INSYNC  0x14
#define STK_NOSYNC  0x15
#define CRC_EOP     0x20 //ok it is a space...

void pulse(int pin, int times);

#ifdef USE_HARDWARE_SPI
#include "SPI.h"
#else

#define SPI_MODE0 0x00

class SPISettings {
  public:
    // clock is in Hz
    SPISettings(uint32_t clock, uint8_t bitOrder, uint8_t dataMode) : clock(clock) {
      (void) bitOrder;
      (void) dataMode;
    };

  private:
    uint32_t clock;

    friend class BitBangedSPI;
};

class BitBangedSPI {
  public:
    void begin() {
      digitalWrite(PIN_SCK, LOW);
      digitalWrite(PIN_MOSI, LOW);
      pinMode(PIN_SCK, OUTPUT);
      pinMode(PIN_MOSI, OUTPUT);
      pinMode(PIN_MISO, INPUT);
    }

    void beginTransaction(SPISettings settings) {
      pulseWidth = (500000 + settings.clock - 1) / settings.clock;
      if (pulseWidth == 0)
        pulseWidth = 1;
    }

    void end() {}

    uint8_t transfer (uint8_t b) {
      for (unsigned int i = 0; i < 8; ++i) {
        digitalWrite(PIN_MOSI, (b & 0x80) ? HIGH : LOW);
        digitalWrite(PIN_SCK, HIGH);
        delayMicroseconds(pulseWidth);
        b = (b << 1) | digitalRead(PIN_MISO);
        digitalWrite(PIN_SCK, LOW); // slow pulse
        delayMicroseconds(pulseWidth);
      }
      return b;
    }

  private:
    unsigned long pulseWidth; // in microseconds
};

static BitBangedSPI SPI;

#endif

void setup() {
  SERIAL.begin(BAUDRATE);

  pinMode(LED_PMODE, OUTPUT);
  pulse(LED_PMODE, 2);
  pinMode(LED_ERR, OUTPUT);
  pulse(LED_ERR, 2);
  pinMode(LED_HB, OUTPUT);
  pulse(LED_HB, 2);

}

int error = 0;
int pmode = 0;
// address for reading and writing, set by 'U' command
unsigned int here;
uint8_t buff[256]; // global block storage

#define beget16(addr) (*addr * 256 + *(addr+1) )
typedef struct param {
  uint8_t devicecode;
  uint8_t revision;
  uint8_t progtype;
  uint8_t parmode;
  uint8_t polling;
  uint8_t selftimed;
  uint8_t lockbytes;
  uint8_t fusebytes;
  uint8_t flashpoll;
  uint16_t eeprompoll;
  uint16_t pagesize;
  uint16_t eepromsize;
  uint32_t flashsize;
}
parameter;

parameter param;

// this provides a heartbeat on pin 9, so you can tell the software is running.
uint8_t hbval = 128;
int8_t hbdelta = 8;
void heartbeat() {
  static unsigned long last_time = 0;
  unsigned long now = millis();
  if ((now - last_time) < 40)
    return;
  last_time = now;
  if (hbval > 192) hbdelta = -hbdelta;
  if (hbval < 32) hbdelta = -hbdelta;
  hbval += hbdelta;
  analogWrite(LED_HB, hbval);
}

static bool rst_active_high;

void reset_target(bool reset) {
  digitalWrite(RESET, ((reset && rst_active_high) || (!reset && !rst_active_high)) ? HIGH : LOW);
}

void loop(void) {
  // is pmode active?
  if (pmode) {
    digitalWrite(LED_PMODE, HIGH);
  } else {
    digitalWrite(LED_PMODE, LOW);
  }
  // is there an error?
  if (error) {
    digitalWrite(LED_ERR, HIGH);
  } else {
    digitalWrite(LED_ERR, LOW);
  }

  // light the heartbeat LED
  heartbeat();
  if (SERIAL.available()) {
    avrisp();
  }
}

uint8_t getch() {
  while (!SERIAL.available());
  return SERIAL.read();
}
void fill(int n) {
  for (int x = 0; x < n; x++) {
    buff[x] = getch();
  }
}

#define PTIME 30
void pulse(int pin, int times) {
  do {
    digitalWrite(pin, HIGH);
    delay(PTIME);
    digitalWrite(pin, LOW);
    delay(PTIME);
  } while (times--);
}

void prog_lamp(int state) {
  if (PROG_FLICKER) {
    digitalWrite(LED_PMODE, state);
  }
}

uint8_t spi_transaction(uint8_t a, uint8_t b, uint8_t c, uint8_t d) {
  SPI.transfer(a);
  SPI.transfer(b);
  SPI.transfer(c);
  return SPI.transfer(d);
}

void empty_reply() {
  if (CRC_EOP == getch()) {
    SERIAL.print((char)STK_INSYNC);
    SERIAL.print((char)STK_OK);
  } else {
    error++;
    SERIAL.print((char)STK_NOSYNC);
  }
}

void breply(uint8_t b) {
  if (CRC_EOP == getch()) {
    SERIAL.print((char)STK_INSYNC);
    SERIAL.print((char)b);
    SERIAL.print((char)STK_OK);
  } else {
    error++;
    SERIAL.print((char)STK_NOSYNC);
  }
}

void get_version(uint8_t c) {
  switch (c) {
    case 0x80:
      breply(HWVER);
      break;
    case 0x81:
      breply(SWMAJ);
      break;
    case 0x82:
      breply(SWMIN);
      break;
    case 0x93:
      breply('S'); // serial programmer
      break;
    default:
      breply(0);
  }
}

void set_parameters() {
  // call this after reading parameter packet into buff[]
  param.devicecode = buff[0];
  param.revision   = buff[1];
  param.progtype   = buff[2];
  param.parmode    = buff[3];
  param.polling    = buff[4];
  param.selftimed  = buff[5];
  param.lockbytes  = buff[6];
  param.fusebytes  = buff[7];
  param.flashpoll  = buff[8];
  // ignore buff[9] (= buff[8])
  // following are 16 bits (big endian)
  param.eeprompoll = beget16(&buff[10]);
  param.pagesize   = beget16(&buff[12]);
  param.eepromsize = beget16(&buff[14]);

  // 32 bits flashsize (big endian)
  param.flashsize = buff[16] * 0x01000000
                    + buff[17] * 0x00010000
                    + buff[18] * 0x00000100
                    + buff[19];

  // AVR devices have active low reset, AT89Sx are active high
  rst_active_high = (param.devicecode >= 0xe0);
}

void start_pmode() {

  // Reset target before driving PIN_SCK or PIN_MOSI

  // SPI.begin() will configure SS as output, so SPI master mode is selected.
  // We have defined RESET as pin 10, which for many Arduinos is not the SS pin.
  // So we have to configure RESET as output here,
  // (reset_target() first sets the correct level)
  reset_target(true);
  pinMode(RESET, OUTPUT);
  SPI.begin();
  SPI.beginTransaction(SPISettings(SPI_CLOCK, MSBFIRST, SPI_MODE0));

  // See AVR datasheets, chapter "SERIAL_PRG Programming Algorithm":

  // Pulse RESET after PIN_SCK is low:
  digitalWrite(PIN_SCK, LOW);
  delay(20); // discharge PIN_SCK, value arbitrarily chosen
  reset_target(false);
  // Pulse must be minimum 2 target CPU clock cycles so 100 usec is ok for CPU
  // speeds above 20 KHz
  delayMicroseconds(100);
  reset_target(true);

  // Send the enable programming command:
  delay(50); // datasheet: must be > 20 msec
  spi_transaction(0xAC, 0x53, 0x00, 0x00);
  pmode = 1;
}

void end_pmode() {
  SPI.end();
  // We're about to take the target out of reset so configure SPI pins as input
  pinMode(PIN_MOSI, INPUT);
  pinMode(PIN_SCK, INPUT);
  reset_target(false);
  pinMode(RESET, INPUT);
  pmode = 0;
}

void universal() {
  uint8_t ch;

  fill(4);
  ch = spi_transaction(buff[0], buff[1], buff[2], buff[3]);
  breply(ch);
}

void flash(uint8_t hilo, unsigned int addr, uint8_t data) {
  spi_transaction(0x40 + 8 * hilo,
                  addr >> 8 & 0xFF,
                  addr & 0xFF,
                  data);
}
void commit(unsigned int addr) {
  if (PROG_FLICKER) {
    prog_lamp(LOW);
  }
  spi_transaction(0x4C, (addr >> 8) & 0xFF, addr & 0xFF, 0);
  if (PROG_FLICKER) {
    delay(PTIME);
    prog_lamp(HIGH);
  }
}

unsigned int current_page() {
  if (param.pagesize == 32) {
    return here & 0xFFFFFFF0;
  }
  if (param.pagesize == 64) {
    return here & 0xFFFFFFE0;
  }
  if (param.pagesize == 128) {
    return here & 0xFFFFFFC0;
  }
  if (param.pagesize == 256) {
    return here & 0xFFFFFF80;
  }
  return here;
}


void write_flash(int length) {
  fill(length);
  if (CRC_EOP == getch()) {
    SERIAL.print((char) STK_INSYNC);
    SERIAL.print((char) write_flash_pages(length));
  } else {
    error++;
    SERIAL.print((char) STK_NOSYNC);
  }
}

uint8_t write_flash_pages(int length) {
  int x = 0;
  unsigned int page = current_page();
  while (x < length) {
    if (page != current_page()) {
      commit(page);
      page = current_page();
    }
    flash(LOW, here, buff[x++]);
    flash(HIGH, here, buff[x++]);
    here++;
  }

  commit(page);

  return STK_OK;
}

#define EECHUNK (32)
uint8_t write_eeprom(unsigned int length) {
  // here is a word address, get the byte address
  unsigned int start = here * 2;
  unsigned int remaining = length;
  if (length > param.eepromsize) {
    error++;
    return STK_FAILED;
  }
  while (remaining > EECHUNK) {
    write_eeprom_chunk(start, EECHUNK);
    start += EECHUNK;
    remaining -= EECHUNK;
  }
  write_eeprom_chunk(start, remaining);
  return STK_OK;
}
// write (length) bytes, (start) is a byte address
uint8_t write_eeprom_chunk(unsigned int start, unsigned int length) {
  // this writes byte-by-byte, page writing may be faster (4 bytes at a time)
  fill(length);
  prog_lamp(LOW);
  for (unsigned int x = 0; x < length; x++) {
    unsigned int addr = start + x;
    spi_transaction(0xC0, (addr >> 8) & 0xFF, addr & 0xFF, buff[x]);
    delay(45);
  }
  prog_lamp(HIGH);
  return STK_OK;
}

void program_page() {
  char result = (char) STK_FAILED;
  unsigned int length = 256 * getch();
  length += getch();
  char memtype = getch();
  // flash memory @here, (length) bytes
  if (memtype == 'F') {
    write_flash(length);
    return;
  }
  if (memtype == 'E') {
    result = (char)write_eeprom(length);
    if (CRC_EOP == getch()) {
      SERIAL.print((char) STK_INSYNC);
      SERIAL.print(result);
    } else {
      error++;
      SERIAL.print((char) STK_NOSYNC);
    }
    return;
  }
  SERIAL.print((char)STK_FAILED);
  return;
}

uint8_t flash_read(uint8_t hilo, unsigned int addr) {
  return spi_transaction(0x20 + hilo * 8,
                         (addr >> 8) & 0xFF,
                         addr & 0xFF,
                         0);
}

char flash_read_page(int length) {
  for (int x = 0; x < length; x += 2) {
    uint8_t low = flash_read(LOW, here);
    SERIAL.print((char) low);
    uint8_t high = flash_read(HIGH, here);
    SERIAL.print((char) high);
    here++;
  }
  return STK_OK;
}

char eeprom_read_page(int length) {
  // here again we have a word address
  int start = here * 2;
  for (int x = 0; x < length; x++) {
    int addr = start + x;
    uint8_t ee = spi_transaction(0xA0, (addr >> 8) & 0xFF, addr & 0xFF, 0xFF);
    SERIAL.print((char) ee);
  }
  return STK_OK;
}

void read_page() {
  char result = (char)STK_FAILED;
  int length = 256 * getch();
  length += getch();
  char memtype = getch();
  if (CRC_EOP != getch()) {
    error++;
    SERIAL.print((char) STK_NOSYNC);
    return;
  }
  SERIAL.print((char) STK_INSYNC);
  if (memtype == 'F') result = flash_read_page(length);
  if (memtype == 'E') result = eeprom_read_page(length);
  SERIAL.print(result);
}

void read_signature() {
  if (CRC_EOP != getch()) {
    error++;
    SERIAL.print((char) STK_NOSYNC);
    return;
  }
  SERIAL.print((char) STK_INSYNC);
  uint8_t high = spi_transaction(0x30, 0x00, 0x00, 0x00);
  SERIAL.print((char) high);
  uint8_t middle = spi_transaction(0x30, 0x00, 0x01, 0x00);
  SERIAL.print((char) middle);
  uint8_t low = spi_transaction(0x30, 0x00, 0x02, 0x00);
  SERIAL.print((char) low);
  SERIAL.print((char) STK_OK);
}
//////////////////////////////////////////
//////////////////////////////////////////


////////////////////////////////////
////////////////////////////////////
void avrisp() {
  uint8_t ch = getch();
  switch (ch) {
    case '0': // signon
      error = 0;
      empty_reply();
      break;
    case '1':
      if (getch() == CRC_EOP) {
        SERIAL.print((char) STK_INSYNC);
        SERIAL.print("AVR ISP");
        SERIAL.print((char) STK_OK);
      }
      else {
        error++;
        SERIAL.print((char) STK_NOSYNC);
      }
      break;
    case 'A':
      get_version(getch());
      break;
    case 'B':
      fill(20);
      set_parameters();
      empty_reply();
      break;
    case 'E': // extended parameters - ignore for now
      fill(5);
      empty_reply();
      break;
    case 'P':
      if (!pmode)
        start_pmode();
      empty_reply();
      break;
    case 'U': // set address (word)
      here = getch();
      here += 256 * getch();
      empty_reply();
      break;

    case 0x60: //STK_PROG_FLASH
      getch(); // low addr
      getch(); // high addr
      empty_reply();
      break;
    case 0x61: //STK_PROG_DATA
      getch(); // data
      empty_reply();
      break;

    case 0x64: //STK_PROG_PAGE
      program_page();
      break;

    case 0x74: //STK_READ_PAGE 't'
      read_page();
      break;

    case 'V': //0x56
      universal();
      break;
    case 'Q': //0x51
      error = 0;
      end_pmode();
      empty_reply();
      break;

    case 0x75: //STK_READ_SIGN 'u'
      read_signature();
      break;

    // expecting a command, not CRC_EOP
    // this is how we can get back in sync
    case CRC_EOP:
      error++;
      SERIAL.print((char) STK_NOSYNC);
      break;

    // anything else we will return STK_UNKNOWN
    default:
      error++;
      if (CRC_EOP == getch())
        SERIAL.print((char)STK_UNKNOWN);
      else
        SERIAL.print((char)STK_NOSYNC);
  }
}

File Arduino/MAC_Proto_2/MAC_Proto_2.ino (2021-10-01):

/*
 * MAC_Proto_2
 * Any questions can be sent to Tyler Richey at tyler777@ksu.edu or tbtaco@hotmail.com
 * Changes that could/should be made in the future:
 *   Changes to some methods broke the Idle Timeout portion of this program making it no longer timeout after 5min. (Closer to 8+ min, but it will timeout at some point)
 *   A switch to specify whether a password should be required was discussed but never implemented on the hardware.  That could easily be added at a later date in code if hardware ever supports it.
 *   Maybe implement a battery percentage check so the device doesn't shut down unexpectedly when the voltage drops low enough.  Disable the Wi-Fi module when there isn't enough voltage to run it.
 *   Not software related at all, but a Contrast potentiometer for the LCD was left off of the current Main Board and could easily be added on future versions.
 *   The column of switches on the Wi-Fi board's latest version was put there as a way to debug stuff and is required to disconnect devices from shared busses for programming purposes.  Putting the SN74LVC245 and 3.3v Regulator on one board, and the ATWINC1500-MR210 on another separate board will let you remove 5 of the 6 switches.  The remaining switch is required to change the IRQ functionality.
 */

#include <time.h>
#include <SPI.h>
#include <WiFi101.h>
#include <LiquidCrystal.h>
#include <Adafruit_NeoPixel.h>
const int wifi_cs = 2; //ATMEGA328P-AU TQFP Pin 32
const int wifi_irq = 3; //1 ^
const int wifi_rst = 4; //2
const int lcd_rs = 5; //9
const int lcd_en = 6; //10
const int lcd_d4 = 7; //11
const int lcd_d5 = 8; //12
const int lcd_d6 = 9; //13
const int lcd_d7 = 10; //14
const int button1 = 16; //25
const int button2 = 15; //24
const int button3 = 14; //23
const int led_signal = 17; //26
const int delayVal = 15; //In milliseconds
const int idleTimeout = 300; //In seconds
const int introScreenSwapTime = 3; //In seconds
const uint32_t introScreenSwapTimeVal = ((introScreenSwapTime * 100) / delayVal) * 10; //Write this in such a way as to not overflow.
const uint32_t idleTimeoutVal = ((idleTimeout * 100) / delayVal) * 10; //^
uint32_t introScreenSwapTimeCounter = 0;
uint32_t timeoutCounter = 0;
const String ssid = "HDStaff"; //Assumes 7 characters long
String pass = "Error"; //Minimum of 8 characters, set in code later on
const int off[] = {0, 0, 0};
const int red[] = {50, 0, 0};
const int yellow[] = {50, 60, 5};
const int green[] = {10, 70, 0};
const int purple[] = {60, 5, 90};
int* currentColor;
const char digits[] = {'0', '1', '2', '3', '4', '5', '6', '7', '8', '9'};
bool button1Pressed = false;
bool button2Pressed = false;
bool button3Pressed = false;
byte mac[6];
bool macSet = false;
bool flashPurple = false;
LiquidCrystal lcd(lcd_rs, lcd_en, lcd_d4, lcd_d5, lcd_d6, lcd_d7);
Adafruit_NeoPixel ledStrip = Adafruit_NeoPixel(1, led_signal, NEO_RGB + NEO_KHZ800);
int status = WL_IDLE_STATUS;
void setup()
{
  ledStrip.begin();
  changeLED(off);
  srand(time(0)); //Not useful as time will always be the same for setup().  Fixed by calling rand() each loop().
  pinMode(button1, INPUT);
  pinMode(button2, INPUT);
  pinMode(button3, INPUT);
  pinMode(led_signal, OUTPUT);
  lcd.begin(16, 2);
  WiFi.setPins(wifi_cs, wifi_irq, wifi_rst); //Wifi also uses MOSI, MISO, and SCK (All 3 shared with ICSP functions)
  changeLED(red);
  if(WiFi.status() == WL_NO_SHIELD)
    printError("Wifi Hardware");
}
void loop()
{
  bool temp1Pressed = digitalRead(button1);
  bool temp2Pressed = digitalRead(button2);
  bool temp3Pressed = digitalRead(button3);
  if(button1Pressed&&!temp1Pressed)
    button1Pressed = false;
  if(button2Pressed&&!temp2Pressed)
    button2Pressed = false;
  if(button3Pressed&&!temp3Pressed)
    button3Pressed = false;
  if(!button1Pressed&&temp1Pressed)
  {
    button1Pressed = true;
    timeoutCounter = 0;
    activateNetwork();
  }
  else if(!button2Pressed&&temp2Pressed)
  {
    button2Pressed = true;
    timeoutCounter = 0;
    getMAC();
  }
  else if(!button3Pressed&&temp3Pressed)
  {
    button3Pressed = true;
    timeoutCounter = 0;
    deactivateNetwork();
  }
  if(timeoutCounter >= idleTimeoutVal) //Use
  {
    deactivateNetwork();
    timeoutCounter = 0;
  }
  status = WiFi.status();
  if(status == WL_AP_CONNECTED)
  {
    printMAC();
    lcd.setCursor(8, 0);
    lcd.print(signalStrength());
    lcd.setCursor(8, 1);
    lcd.print(pass);
    if(flashPurple)
    {
      changeLED(purple); //Pauses all chip functionality while I do this block, but it is short enough to not matter much...
      delay(100);
      changeLED(green);
      delay(200);
      changeLED(purple);
      delay(100);
      changeLED(green);
      flashPurple = false;
    }
    else
      changeLED(green);
  }
  else if(status == WL_AP_LISTENING)
  {
    if(macSet)
    {
      printMAC();
      lcd.setCursor(8, 0);
      lcd.print(' ' + ssid);
      lcd.setCursor(8, 1);
      lcd.print(pass);
    }
    else
      printLCD("Network: "+ssid, "PW:     "+pass);
    changeLED(yellow);
  }
  else
  {
    if(timeoutCounter%introScreenSwapTimeVal==0)
    {
      introScreenSwapTimeCounter++;
      if(introScreenSwapTimeCounter%2==1)
        printLCD("MAC Proto Ver. 2", "S. Design Team 1");
      else
        printLCD("Press Button1 To", "Activate Network");
    }
    if(flashPurple && status != WL_AP_CONNECTED)
      flashPurple = false;
    changeLED(red);
  }
  rand(); //Call this every cycle to help fix initial randomization
  timeoutCounter+=1;
  delay(delayVal);
}
void activateNetwork()
{
  if(status != WL_AP_LISTENING && status != WL_AP_CONNECTED)
  {
    WiFiServer server(80);
    pass = "Pass"; //WPA2 REQUIRES 8+ CHARACTERS FOR A PASSWORD!
    for(int i = 0; i < 4; i++) //Example password: Pass8329
    {
      int r = rand() % 10;
      pass += digits[r];
    }
    char ssidTemp[ssid.length()+1];
    char passTemp[8];
    //status = WiFi.beginAP(stringToChars(ssidTemp, ssid), stringToChars(passTemp, pass));
    status = WiFi.beginAP(stringToChars(ssidTemp, ssid));
    //pass = " Nothing";
    pass = "        ";
    server.begin();
  }
  if(status != WL_AP_LISTENING && status != WL_AP_CONNECTED)
    printError("Creation Failed (AP)");
}
void getMAC()
{
  status = WiFi.status();
  if(status == WL_AP_CONNECTED)
  {
    WiFi.APClientMacAddress(mac);
    macSet = true;
    flashPurple = true;
  }
}
void deactivateNetwork()
{
  if(status != WL_IDLE_STATUS)
  {
    WiFi.disconnect();
    WiFi.end();
  }
  status = WL_IDLE_STATUS;
}
void printLCD(String s1, String s2)
{
  lcd.setCursor(0, 0);
  lcd.print(s1);
  for(int i = s1.length(); i < 16; i++)
    lcd.print(' ');
  lcd.setCursor(0, 1);
  lcd.print(s2);
  for(int i = s2.length(); i < 16; i++)
    lcd.print(' ');
}
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
